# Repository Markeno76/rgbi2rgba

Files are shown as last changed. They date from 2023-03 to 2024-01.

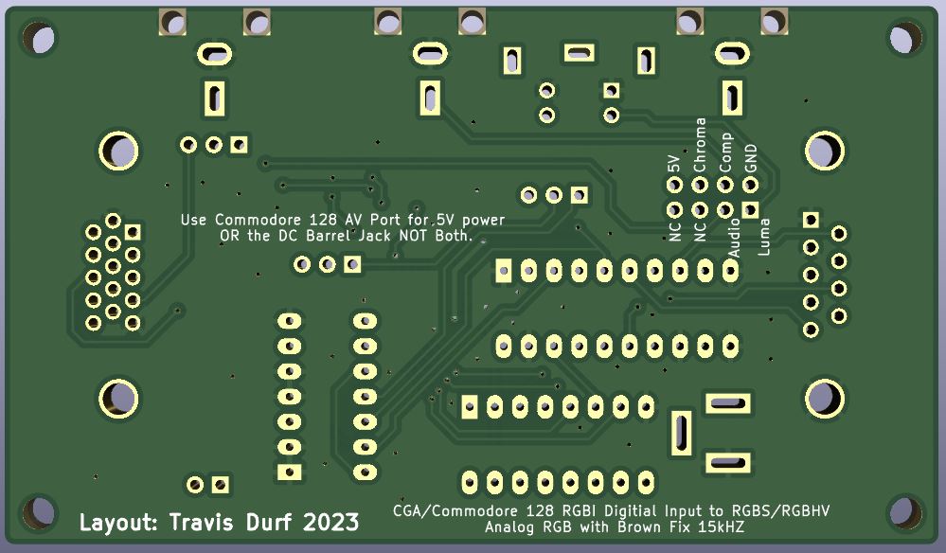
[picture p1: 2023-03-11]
images/botview13.JPG

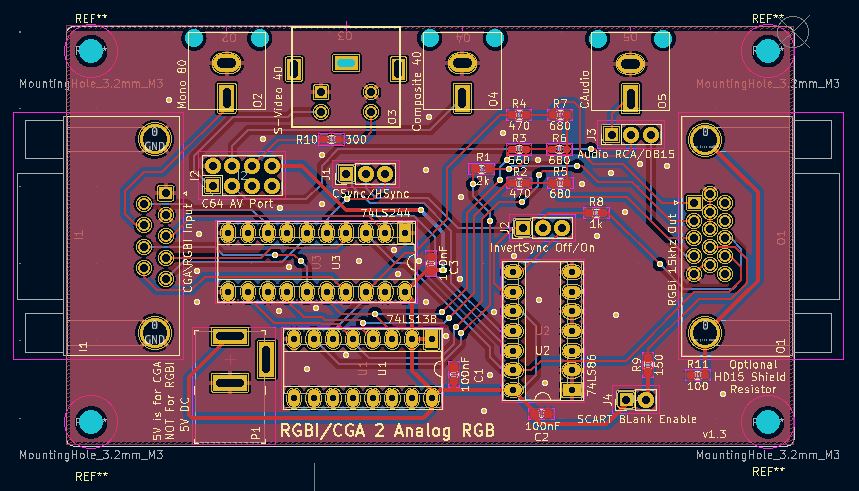
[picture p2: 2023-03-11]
images/board13.JPG

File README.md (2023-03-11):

# rgbi2rgba
Commodore 128 RGBI / CGA  to Analog RGB

I made this project to be a RGBI/CGA (RGB Digital) to RGBA (RGB Analog) for the Commodore 128 RGBI 80 Column Video output.  This also works with CGA Video being the same type of video signal.  Both are Digital RGB with an Intensity signal that provides Light/Dark for each of the RGB Signals.  CGA/RGBI both share the "Brown" instead of "Dark Yellow" output.  More basic methods of converting the RGBI to Analog RGB can just ignore the Intensity signal, but that drops half the colors.  It can also ignore the Brown Fix.  This converter includes use of the Intensity Signals and does the Brown fix.

You can view the blog post about the adapter here: https://hobbytronics.home.blog/2023/02/07/commodore-128-80-column-or-cga-rgbi-to-rgba-15khz-vga-adapter-part-2/

I based it on various schematics I found online for a combination of CGA and Commodore 128 RGBI adapters.  The adapter outputs either RGBS or RGBHV, but at 15khz so it was setup to go into a SCART to HDMI Adapter.  It also can work with a GBS Control which takes RGBHV or RGBS and outputs standard VGA output (RGBHV at 31khz).

For this revision of the Adapter I have extended the options for the Commodore 128.  The prototype back in 2019 used the Commodore AV Port for power and passed through Audio and Composite 40 Column Video.  The new version now has passthrough output for Monochrome 80 Column mode (it was easy to include), Composite 40 Column Video, Audio Output, and S-Video 40 Column Video.  When doing that with the Commodore 128 it gets 5V from the Commodore AV Port.  I added a DC Power Jack that can be used to make it easy to connect the adapter up as an adapter for IBM CGA.  Don't connect up both the Commodore AV Port power and the DC Power Jack please..

When only using the adapter for IBM CGA, you can omit the 3 RCA Jacks and the S-Video Jack. There are some header pins that can be ommited as well for the Commodore AV port.  The board has some onboard jumpers to switch between RGBS and RGBHV.  There is also a Sync Invert option for use with the RGBS mode.  I can not remember why I added the sync invert option, but I think it had something to do with GBS boards at this time.

The board uses a DBHD15 VGA type port for 80 Column output.  This can use a standard VGA cable and go into the GBS Control.  It has 2 special use pins I used for my SCART to HDMI device, it has a 5V Blanking signal and outputs Audio to a a pin on the HD15 if the jumpers are set for that.  When using it with the GBS Control those both should be disabled.

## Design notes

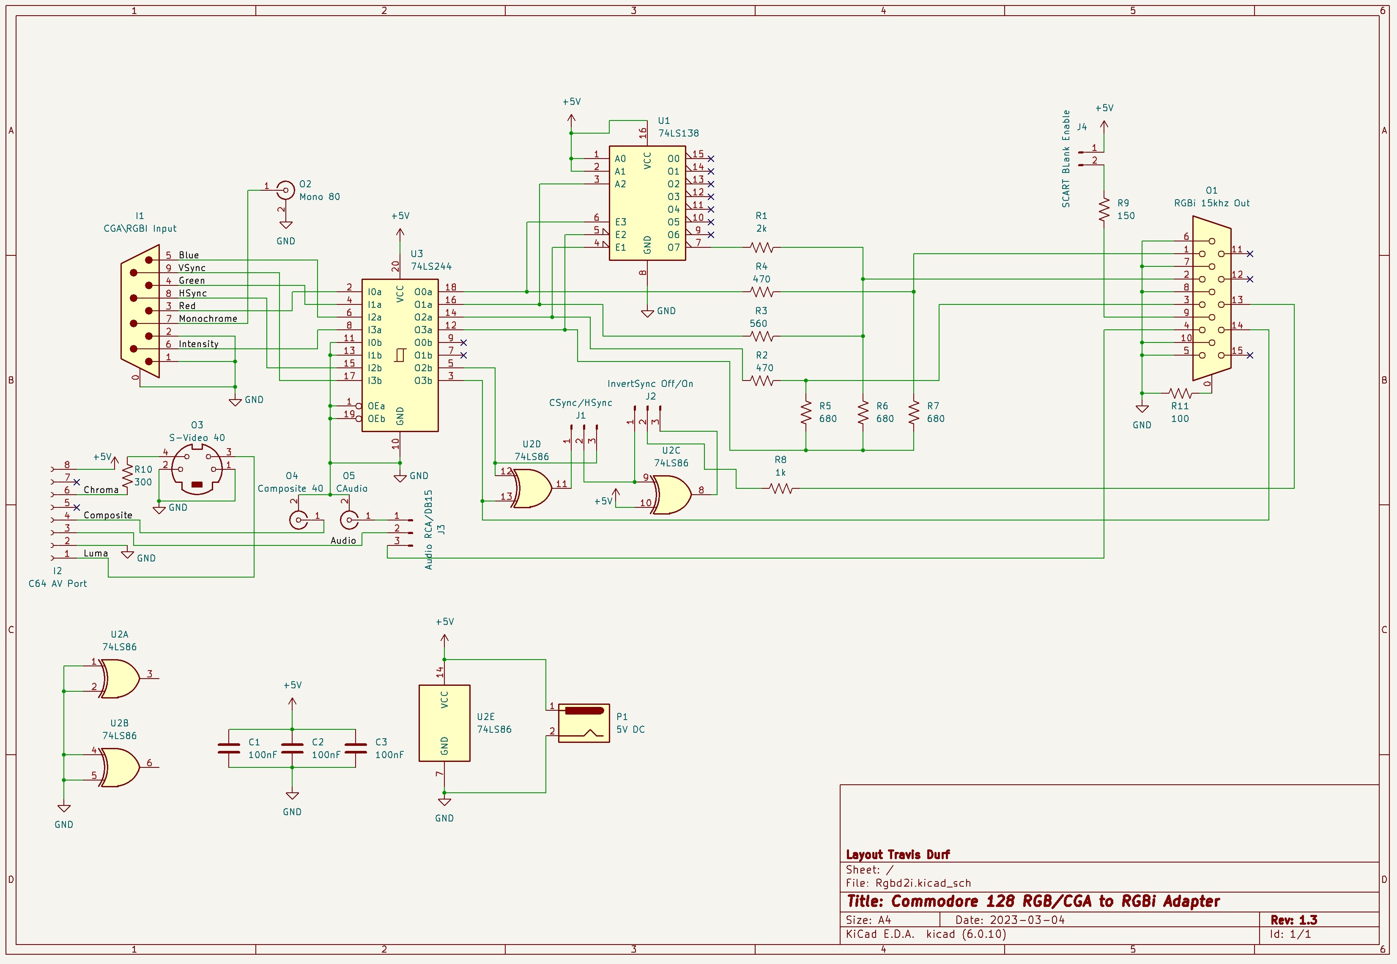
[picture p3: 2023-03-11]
docs/80colschematic13.jpg

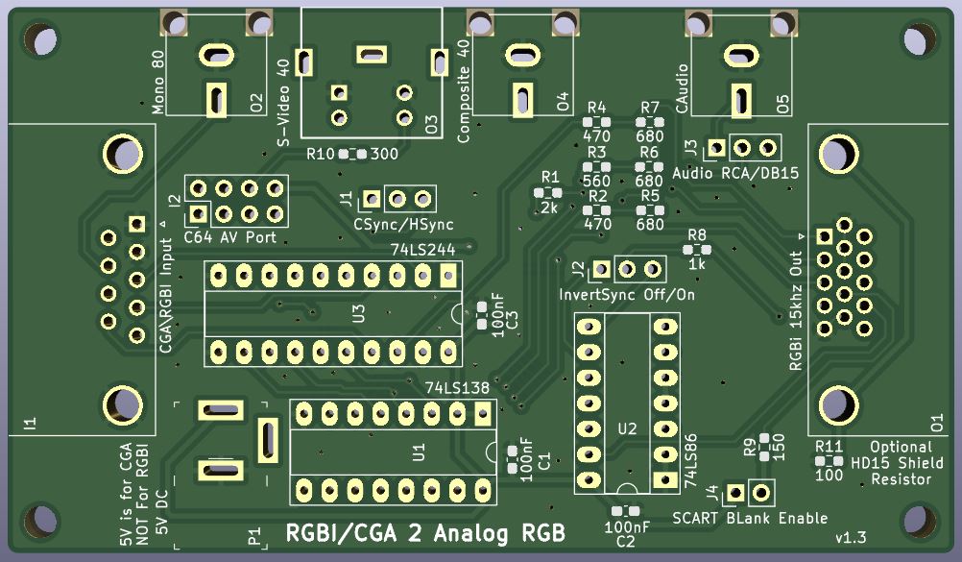
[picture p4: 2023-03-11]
images/topview13.JPG

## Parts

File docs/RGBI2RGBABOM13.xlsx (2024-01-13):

RGBI2RGBA Adapter v1.3 BOM
Qty | Description
1 | 150 Ohm 0603 Resistor | https://www.digikey.com/en/products/detail/walsin-technology-corporation/WR06X1500FTL/13239274
1 | 300 Ohm 0603 Resistor | https://www.digikey.com/en/products/detail/yageo/RC0603JR-07300RL/726765
2 | 470 Ohm 0603 Resistor | https://www.digikey.com/en/products/detail/walsin-technology-corporation/WR06X4700FTL/13240646
1 | 560 Ohm 0603 Resistor | https://www.digikey.com/en/products/detail/yageo/RC0603JR-07560RL/726805
3 | 680 Ohm 0603 Resistor | https://www.digikey.com/en/products/detail/walsin-technology-corporation/WR06X6800FTL/13240808
1 | 1k Ohm 0603 Resistor | https://www.digikey.com/en/products/detail/walsin-technology-corporation/WR06X102-JTL/13241138
1 | 2k Ohm 0603 Resistor | https://www.digikey.com/en/products/detail/yageo/RC0603JR-072KL/726726
3 | 0.1 uF (100nF) 0603 Capacitor | https://www.digikey.com/en/products/detail/samsung-electro-mechanics/CL10B104KB8NNWC/3887593
1 | RCA Jack Black | https://www.digikey.com/en/products/detail/kycon-inc/KLPX-0848A-2-B/9990118
1 | RCA Jack Red | https://www.digikey.com/en/products/detail/kycon-inc/klpx-0848a-2-r/9990119
1 | RCA Jack Yellow | https://www.digikey.com/en/products/detail/kycon-inc/klpx-0848a-2-y/10246556
1 | 4pin Mini Din | https://www.digikey.com/en/products/detail/kycon-inc/KMDGX-4S-BS/9990073
1 | DSUB DE9 Male (Backset 10.4mm) | https://www.digikey.com/en/products/detail/amphenol-cs-fci/LD09P13A4GX00LF/4997285
1 | DSUB HD15 Female (Backset 8.89mm) | https://www.digikey.com/en/products/detail/edac-inc/634-015-263-032/806194
1 | 74LC244 | https://www.digikey.com/en/products/detail/texas-instruments/SN74LS244N/277299
1 | 74LS138 | https://www.digikey.com/en/products/detail/texas-instruments/SN74LS138N/277285
1 | 74LS86 | https://www.digikey.com/en/products/detail/texas-instruments/SN74LS86AN/277315
 | 2.5x5.5mm Barrel Jack | Standard 2.5mm x 5.5mm barrel pcb mount jack.
 | 2.54mm Pin Header Strip
 | 2.54mm jumpers
 | IC Sockets for the ICs | If you want to use IC Sockets
 | 8 Pin “U” Shaped DIN Connector Male | If you are using for a C128 RGBI provides 5V Power, SID Audio, 40 Vic Video etc
Note: | The 74LS86 is for making Csync, if you won’t be using the Csync you don’t need it installed.

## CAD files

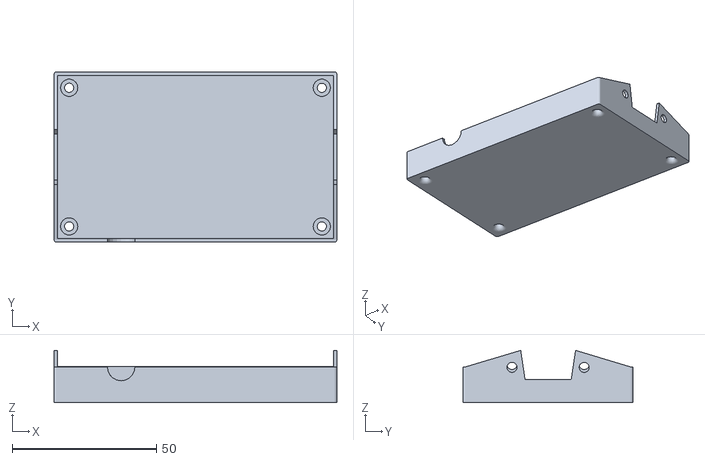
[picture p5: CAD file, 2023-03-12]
3dmodel/Rgbd2i.6cgabot.stl
98.0 x 59.0 x 18.1

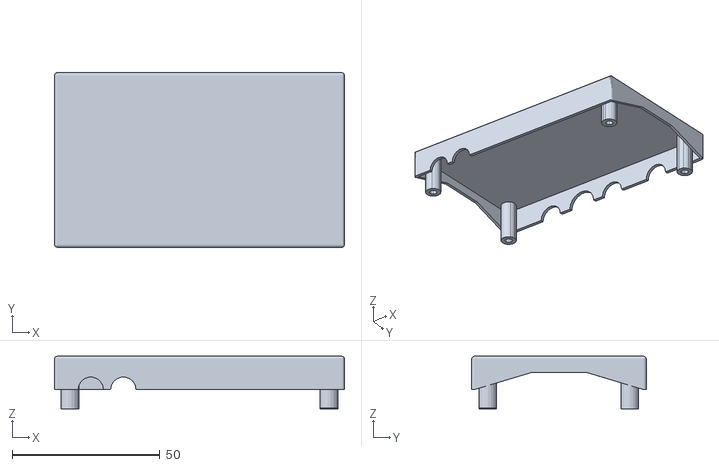
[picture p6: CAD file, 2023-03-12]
3dmodel/Rgbd2i.7c128top.stl
98.0 x 59.0 x 17.8

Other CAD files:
3dmodel/Rgbd2i.7c128bot.stl
3dmodel/Rgbd2i.6alltop.stl
3dmodel/Rgbd2i.6cgatop.stl
3dmodel/Rgbd2i.6allbot.stl

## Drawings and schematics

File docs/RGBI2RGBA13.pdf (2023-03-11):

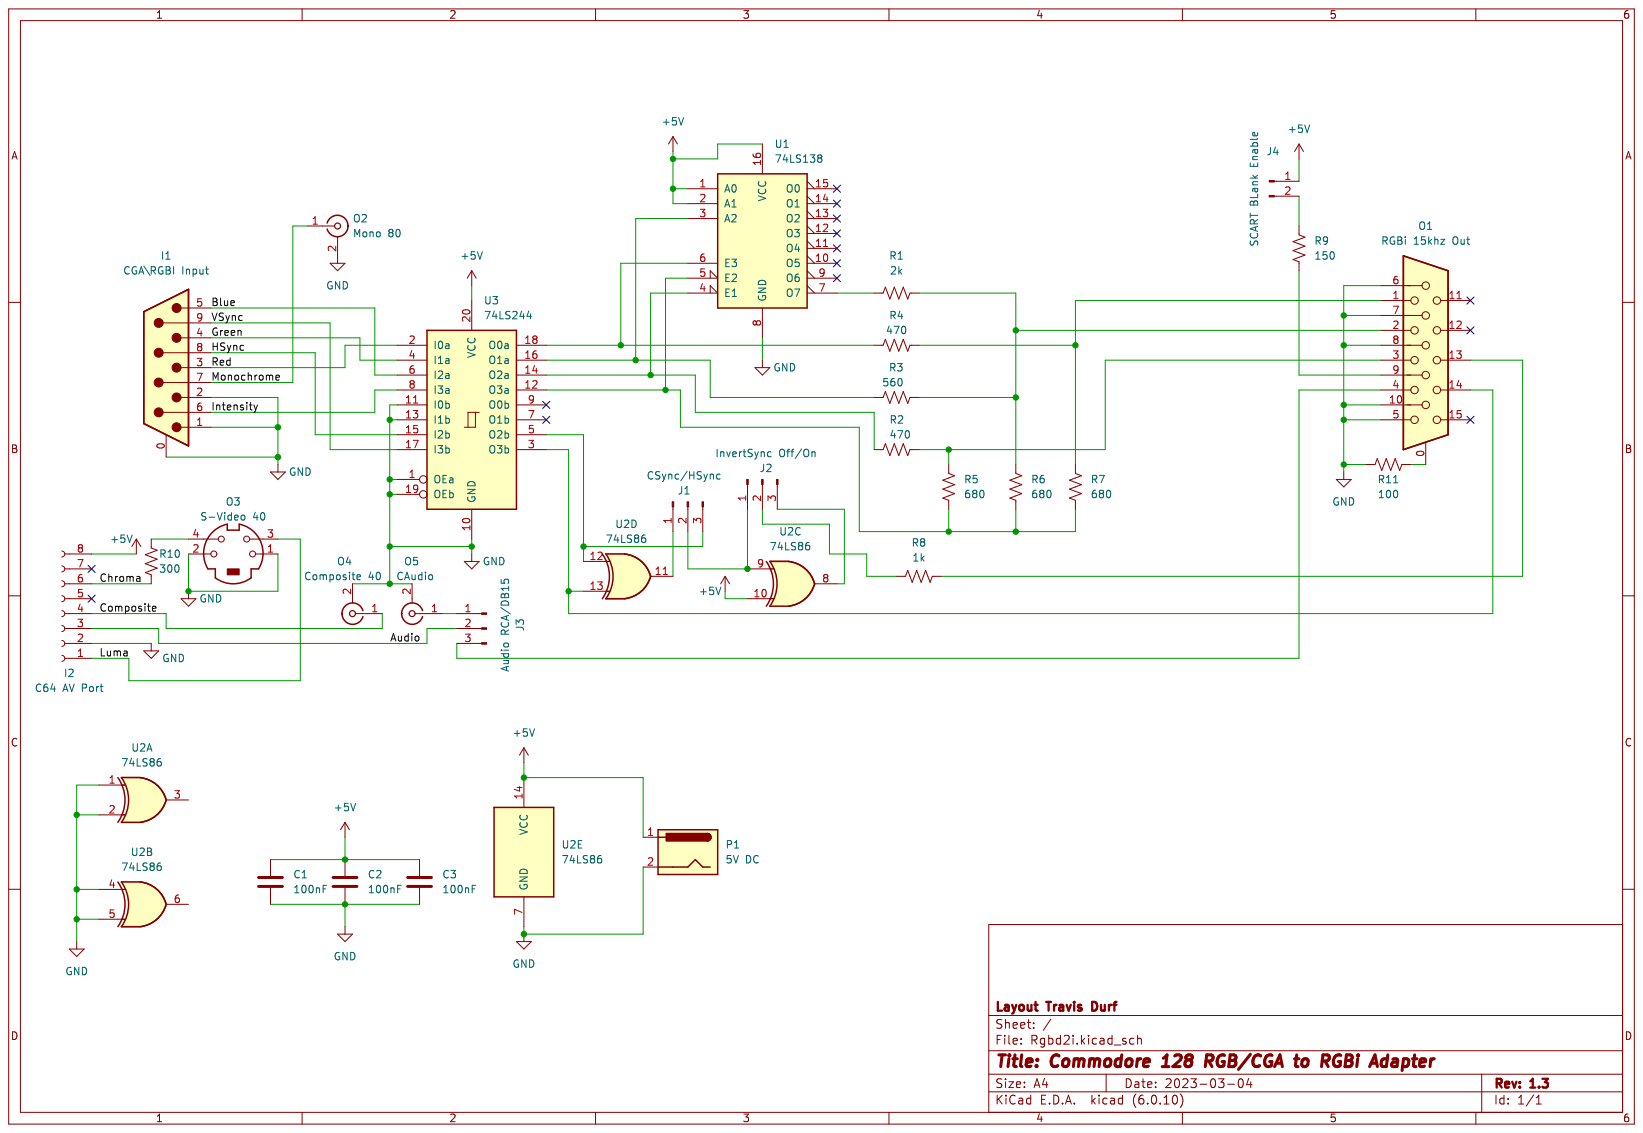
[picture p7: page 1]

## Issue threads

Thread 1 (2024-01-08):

BOM file

olivierjan, 2024-01-08:
Hi, first, many thanks for this great design.
I've been looking at the repo and I can't seem to find the BOM for this project. There is one on your website (https://hobbytronics.home.blog/2023/02/07/commodore-128-80-column-or-cga-rgbi-to-rgba-15khz-vga-adapter-part-2/) but is it up-to-date ?
Regards,
Olivier

t9999clint, 2024-01-08:
I'm also looking to build one of these to use with my PCjr and my GBS-Control. A BOM would be super handy for this.

Markeno76, 2024-01-12:
The "Parts list" section on Part 2 is accurate for the current design.  The changes from from the board shown in the article are corrections to the layout etc, not parts changes.   I have switched to using the adapter with a GBS Control, as I found the SCART to HDMI adapter I had been using previously was not being stable on certain programs, I don't know why.  It is also reported as laggy, so I switched to the GBS Control.  The GBS Control doesn't need the CSync function and I set up the adapter to not do CSync.

Markeno76, 2024-01-13:
BOM Added that is a bit more complete than the Blog post, but I can't say where to get a 8Pin "U" DIN connector if you want to use it with the C128.  The Power Jack is not specific to a part number, but all the generic 2.5x5.5mm through hole mount power jacks I have come across fit the footprint.

Closed 2024-01-13.

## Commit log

2023-03-11 Initial Beta files.
    V1.3 is currently still being verified. The revised 3d models for the case are being test printed now. The first version of the 3d model has openings for all ports. I expect to release a version of t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
    [Rgbd2i.5bot.stl, Rgbd2i.5top.stl]
2023-03-12 Revised 3d Case Model Files.
    [Rgbd2i.5bot.stl, Rgbd2i.5top.stl, Rgbd2i.6allbot.stl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]
2024-01-13 Initial BOM
    Added BOM. Mostly complete.
    [RGBI2RGBABOM13.xlsx]
